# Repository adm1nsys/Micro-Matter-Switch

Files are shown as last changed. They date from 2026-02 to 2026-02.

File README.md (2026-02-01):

# Micro-Matter-Switch
Micro Matter Switch (MMS) is a small compact switch based on ESP32 C6 Xiao<br>
<b>Note:</b> Code based on <a href="https://github.com/espressif/arduino-esp32/tree/master/libraries/Matter/examples">Espressif</a> examples but it's heavily restructured by <a href="https://github.com/adm1nsys">adm1nsys</a>.
<h1>Board</h1>
For this project I have used ESP32 C6 Xiao because it's realy tiny. This project can be compiled for another ESP32 but you have to make new case and inicialize your pins. 
<h3>Pinout of ESP 32 C6 Xiao</h3>
esp32c6 xiao pinout
<a href="https://wiki.seeedstudio.com/xiao_esp32c6_getting_started/">ESP32 C6 Xiao WiKi</a>
<h1>Case</h1>
As a material I recomend to use PETG becouse it's easy to print, enough strong and has a lot of colours.<br>
<h3>Download Case:</h3>
<a href="https://github.com/adm1nsys/Micro-Matter-Switch/tree/main/Case">Git</a><br>
<h3>Screws:</h3>
This case was made for screws M3x12mm
<h2>Quick Start</h2>
Download <a href="https://www.arduino.cc/en/software/">Arduino IDE for MAC/Linux/Windows10/11</a> <b>NOT</b> Arduino App Lab.<br>
<h3>Setup IDE</h3>

<ol>
  <li>Open Arduino IDE</li>
  <li>Open Preferences (Above)</li>
  <li>Add in board manager URL - URL of board and click OK
      
    https://espressif.github.io/arduino-esp32/package_esp32_index.json
  menu
  </li>
  <li>Download the XIAO ESP32C6 board package.<br>
  board package</li>
  <li>Choose your board as a target (above)<br>
  choose board</li>
  <li>Download this repo, open MMS.ino file</li>
  <li>Click on Upload or click Command(CMD) MAC / Control(Ctrl) WIN + U</li>
</ol>
<h1>Add to Ecosystem</h1>
Scan QR Code below to add or enter code <b>3497-011-2332</b> <br>
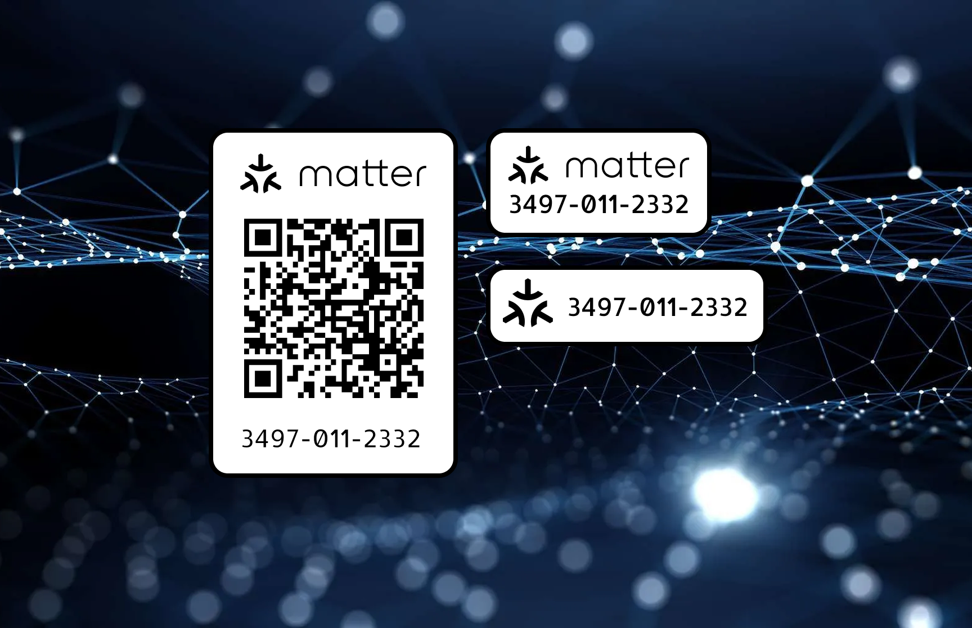
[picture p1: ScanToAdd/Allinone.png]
all qrcodes

<a href="https://project-chip.github.io/connectedhomeip/qrcode.html?data=MT:Y.K9042C00KA0648G00">https://project-chip.github.io/connectedhomeip/qrcode.html?data=MT:Y.K9042C00KA0648G00</a>

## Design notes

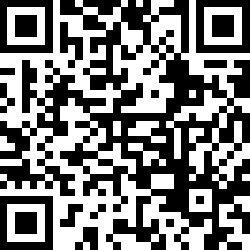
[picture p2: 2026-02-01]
ScanToAdd/Payload MT Y.K9042C00KA0648G00.png

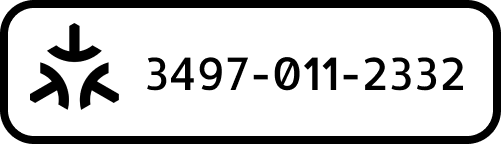
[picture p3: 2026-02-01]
ScanToAdd/Code2.png

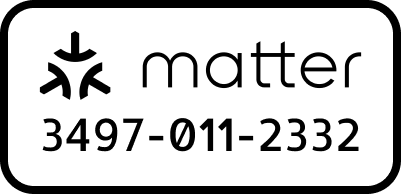
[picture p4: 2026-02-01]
ScanToAdd/Code1.png

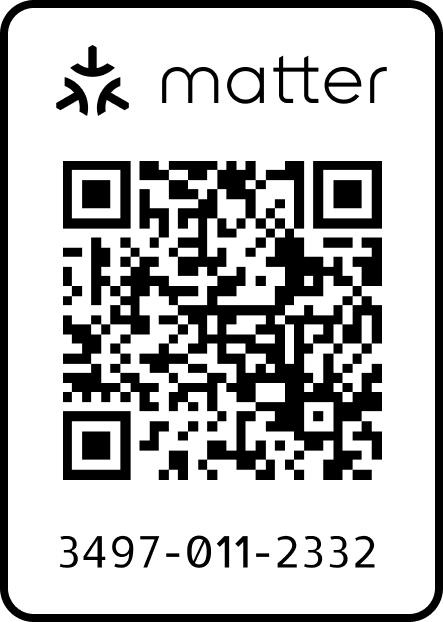
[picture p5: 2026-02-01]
ScanToAdd/QR.png

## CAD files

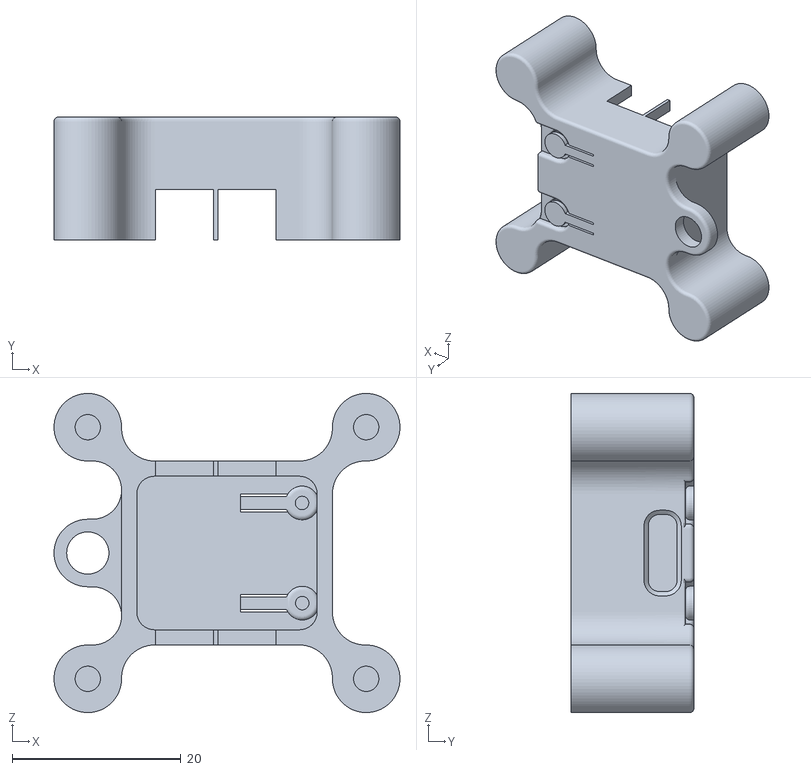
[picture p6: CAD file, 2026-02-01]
Case/CaseESP.stl
41.0 x 14.5 x 37.8

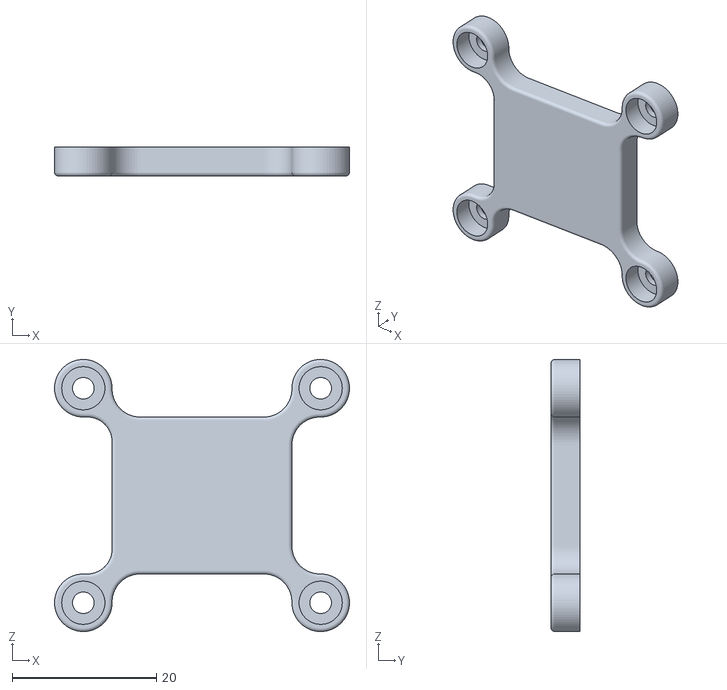
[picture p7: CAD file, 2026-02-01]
Case/CaseESPtop.stl
41.0 x 4.00 x 37.8

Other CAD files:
Case/CaseESP.f3z
Case/CaseESP.obj
Case/CaseESPtop.obj

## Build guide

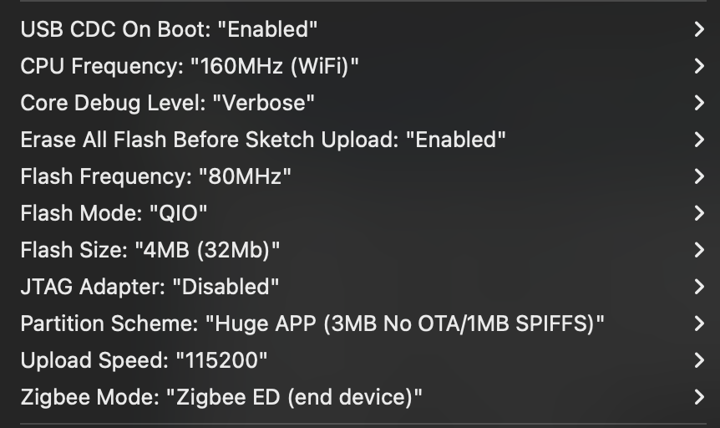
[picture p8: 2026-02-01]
build settings.png

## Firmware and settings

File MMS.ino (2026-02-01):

// ===== Structures =====
struct DeviceDef {
  void (*logicFn)(void*);
  void (*setupFn)(void*);
  void (*loopFn)(void*);
};
// ===== include =====
#include <include.h>
// ===== BLE OR WiFi =====
#if BLE_MODE
  #define CONFIG_ENABLE_CHIPOBLE 1
  #define CHIP_DEVICE_CONFIG_ENABLE_THREAD 1
  #define CHIP_DEVICE_CONFIG_ENABLE_WIFI 0
#else
#if !CONFIG_ENABLE_CHIPOBLE
  #define CONFIG_ENABLE_CHIPOBLE 0
  #define CHIP_DEVICE_CONFIG_ENABLE_THREAD 0
  #define CHIP_DEVICE_CONFIG_ENABLE_WIFI 1
  #include <WiFi.h>
#endif
#endif
// ===== Logic =====
static inline void beforeSetup() {
  for (size_t i = 0; i < devicesCount; ++i) devices[i].logicFn(nullptr);
}
static inline void SetupScripts() {
  for (size_t i = 0; i < devicesCount; ++i) devices[i].setupFn(nullptr);
}
static inline void LoopScripts() {
  for (size_t i = 0; i < devicesCount; ++i) devices[i].loopFn(nullptr);
}
void startSNTP() {
  // KYIV: EET/EEST
  configTzTime("EET-2EEST,M3.5.0/3,M10.5.0/4", "pool.ntp.org", "time.google.com");
}
// ===== Arduino Core =====
bool blinkStep(uint8_t pin) {
  static uint8_t phase = 0;              // 0 — no blink, 1..6 — 3 cycles of 50ms (HIGH/LOW)
  static unsigned long t = 0;
  const unsigned long stepMs = 50;

  unsigned long now = millis();
  if (phase == 0) {                       // Start of blinks
    digitalWrite(pin, HIGH);
    t = now;
    phase = 1;
    return false;
  }
  if (now - t >= stepMs) {                // The next step every 50ms
    t += stepMs;
    digitalWrite(pin, (phase & 1) ? LOW : HIGH);
    if (++phase > 6) {                    // 3 cycles completed
      digitalWrite(pin, LOW);
      phase = 0;
      return true;                        // signal: pause for 200ms
    }
  }
  return false;
}
// ===== void setup =====
void setup(){
  // Serial.begin and pins
  Serial.begin(115200);
  pinMode(buttonPin, INPUT_PULLUP);
  pinMode(ledPin, OUTPUT);
  // ===== Before Setup Logic =====
  beforeSetup();
  // CONFIG_ENABLE_CHIPOBLE is enabled when BLE is used to commission the Matter Network
#if !CONFIG_ENABLE_CHIPOBLE
  // Manually connect to WiFi
  // Before Matter.begin():
  WiFi.begin(ssid, password);
  // Wait for connection
  Serial.println();
  Serial.print("Connecting to ");
  Serial.println(ssid);
  while (WiFi.status() != WL_CONNECTED) {
    Serial.print('.');
    delay(500);
  }
#endif

  Matter.onEvent(onMatterEvent);
  Matter.begin();

  // ===== Void Setup Logic =====
  SetupScripts();
  if (!Matter.isDeviceCommissioned()) {
    Serial.println("\n=== Matter Over WiFi (BLE commissioning) ===");
    Serial.printf("Manual pairing code: %s\n", Matter.getManualPairingCode().c_str());
    Serial.printf("QR code URL:        %s\n", Matter.getOnboardingQRCodeUrl().c_str());
    OnOffLight.updateAccessory(); /// NOTE: REMOVE
  } else {
    // Resumed
    Serial.printf("Resumed");
    // Add update logic to SetupScripts
  }

Serial.println(String("Matter.isDeviceCommissioned() Is connected? ") + Matter.isDeviceCommissioned());

}
// ===== void loop =====
void loop(){
  // ===== Paiting Mode =====
  static uint32_t lastNote = 0;
  if (!Matter.isDeviceCommissioned() && millis() - lastNote > 5000) {
    Serial.println("Waiting for commissioning…");
    lastNote = millis();
  }



// Pairing led blinking
if (!Matter.isDeviceCommissioned()) {
  if (blinkStep(ledPin)) {
    delay(200);
    UserEventsConnect();
  }
}

  // BOOT Button: Click calls UserEventsBootClick(); and HOLD for 5sec making Decommission
  if (digitalRead(buttonPin) == LOW && !btn_down) {
    btn_down = true;
    btn_ts = millis();
  }
  uint32_t dt = millis() - btn_ts;
  if (btn_down && dt > debounceMs && digitalRead(buttonPin) == HIGH) {
    btn_down = false;
    UserEventsBootClick();
  }
  if (btn_down && dt > decommissionHoldMs) {
    Serial.println("Decommissioning…");
    UserEventsDecommissioning();
    Matter.decommission();
    btn_ts = millis();
  }

  // ===== Void Loop Logic =====
  LoopScripts();
}

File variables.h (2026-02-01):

#pragma once

// ===== BLE MODE =====
#define BLE_MODE 1 // true 1 / false 0
// ===== if BLE MODE 0 =====
#if !BLE_MODE
  const char *ssid = "SSID";          // Change this to your WiFi SSID
  const char *password = "PASSWORD";  // Change this to your WiFi password
#endif

const uint32_t decommissionHoldMs = 5000;
const uint32_t debounceMs = 250;
bool btn_down = false;
uint32_t btn_ts = 0;
bool blinkStep(uint8_t pin);
volatile bool identifyFlag = false;     // Flag to start the Blink when in Identify state

// -------- Buttons pins --------
constexpr uint8_t BTN1_IN   = 18; // D10 (to GND), active LOW
constexpr uint8_t BTN2_IN   = 17; // D7  -> input with PULLUP
constexpr uint8_t BTN2_SINK = 20; // D9  -> output LOW
constexpr uint8_t BTN3_IN   = 1;  // G1  -> input with PULLUP
constexpr uint8_t BTN3_SINK = 21; // D3  -> output LOW
constexpr uint8_t BTN4_IN   = 22; // D4  -> input with PULLUP
constexpr uint8_t BTN4_SINK = 16; // D6  -> output LOW

// ===== LED on Board and BOOT Button =====
#ifdef LED_BUILTIN
  const uint8_t ledPin = LED_BUILTIN;
#else
  const uint8_t ledPin = 2;  // Set your pin here if your board has not defined LED_BUILTIN
#endif
const uint8_t buttonPin = BOOT_PIN;

uint32_t button1_time_stamp = 0;                // debouncing control
bool button1_state = false;                     // false = released | true = pressed

uint32_t button2_time_stamp = 0;                // debouncing control
bool button2_state = false;                     // false = released | true = pressed

uint32_t button3_time_stamp = 0;                // debouncing control
bool button3_state = false;                     // false = released | true = pressed

uint32_t button4_time_stamp = 0;                // debouncing control
bool button4_state = false;                     // false = released | true = pressed

const uint32_t debouceTime = 250;              // button debouncing time (ms)
const uint32_t decommissioningTimeout = 5000;  // keep the button pressed for 5s, or longer, to decommission

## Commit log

2026-02-01 Add quick start guide to README
    Added quick start instructions for setting up the Arduino IDE and XIAO ESP32C6 board.
2026-11-02 Website (docs/), README in Markdown with banner, wiring and code layout
2026-11-05 Workflows: Website, Build, and Release that attaches the firmware when a release is published
2026-11-05 Remove the firmware CI: without the board it proves nothing
2026-11-06 Photos of the switch: assembled and opened, in the README and on the site
2026-11-06 Three more photos (other side, without the case, the board) and a note on the buttons with broken-off legs
2026-11-06 Rename the sketch to Micro-Matter-Switch.ino, full board settings with a screenshot, note on esp32 3.3.0
